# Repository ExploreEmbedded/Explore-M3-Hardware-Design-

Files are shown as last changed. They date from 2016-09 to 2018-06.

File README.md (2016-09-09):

# Explore-M3-Hardware-Design-

Explore M3 is a feature rich ARM Cortex M3 development board. It can help you prototype ideas faster with Arduino and take them beyond, with bare metal programming, RTOS support and lower power modes if need be. All the source-code and hardware design files are open-source including the on board boot-loader. This makes it easy in using the board/chip in your custom designs

explore m3

We are currently crowdfunding the board, click on the link below to support.
https://www.crowdsupply.com/explore-embedded/explore-m3

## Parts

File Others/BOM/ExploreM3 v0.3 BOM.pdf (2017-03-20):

Id Designator | | Package | units | Designation | Quantities
1 | P6 | 2.54 mm Pitch 8X1 | 1 | Male Pin headers | 50
2 | P7,P5 | 2.54 mm Pitch 20X1 | 1 | Male Pin headers | 50
3 | P1 | 2.54 mm Pitch 5X2 | 1 | Male Pin headers | 50
5 | D1,D3 | 0603 Package | 3 | Blue LED | 150
6 | D2 | 0603 Package | 1 | Red LED | 50
7 | F1 | 1206 Package | 1 | FUSE | 50
10 | Y1 | SMD ,3.2mm x 1.5mm | 1 | 32.768KHz Crystal | 50
11 | L1 | 0805 Package | 1 | Multilayer Ferrite Bead (7 ohm) | 50
14 | U2 | SOT-23-3 | 1 | BSS84 MOSFET | 50
17 | C5,C1,C2,C6,C7,C8 | 0603 Package | 6 | 0.1uF ceramic capacitors | 300
18 | R4,R5 | 0603 Package | 2 | 100E Resistors | 100
19 | C3,C4,C16,C18 | 0603 Package | 4 | 22pf Ceramic Capacitors | 200
20 | C10,C11 | 0603 Package | 2 | 18pF Ceramic Capacitors | 100
21 | C12 | 0603 Package | 1 | 1uF Ceramic Capacitors | 50
22 | C14 | 0603 Package | 1 | 0.1uF ceramic capacitors | 50
23 | C15 | 0603 Package | 1 | 2.2uf Ceramic Capacitors | 50
24 | R1,R8,R9,R10,R11,R12,R13,R20 | 0603 Package | 8 | 10K Resistors | 400
25 | R2,R19,R21,R22 | 0603 Package | 4 | 1K Resistors | 200
26 | R3 | 0603 Package | 1 | 150E Resistors | 50
27 | R6 | 0603 Package | 1 | 100K Resistors | 50
28 | R7,R14 | 0603 Package | 2 | 33R Resistors | 100
29 | R15 | 0603 Package | 1 | 1.5K Resistors | 50
Explore M3 v0.3 | Quantity | 50

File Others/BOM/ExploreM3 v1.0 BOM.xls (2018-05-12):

 | Explore M3 v1.0 | Quantity
Id | Designator | Package | Designation | Quantities | Link
1 | P6 | 2.54 mm Pitch 8X1 | Male Pin headers | 120
2 | P7,P5 | 2.54 mm Pitch 20X1 | Male Pin headers | 230
3 | P1 | 2.54 mm Pitch 5X2 | Male Pin headers | 120
4 | U3 | SMD | Micro USB connector | 50 | https://www.aliexpress.com/item/100pc-Micro-USB-5pin-B-type-0-8mm-Female-Connector-For-Mobile-Phone-Micro-USB-Jack/32648674955.html
7 | F1 | 1206 Package | FUSE | 120 | https://ae01.alicdn.com/kf/HTB1f23bNFXXXXbpXFXXq6xXFXXX8/10-Pcs-Per-Lot-Littelfuse-SMD-SMT-1206-Fast-Acting-Fuse-0-5A-500mA-63V-0466.jpg_640x640.jpg
8 | U1 | LQFP-100 | LPC1768FBD100 | 110
9 | U4 | SOT-23-5 | AP2112K | 120 | https://www.aliexpress.com/item/Brand-new-original-SOT23-5-AP2112K-3-3TRG1-patch-3-3V-LDO-600MA-regulator/32605944979.html
10 | Y1 | SMD ,3.2mm x 1.5mm | 32.768KHz Crystal | 115 | https://www.aliexpress.com/item/CC7V-T1K-FC-135-CM315-DST310S-3215-2P-32-768K-32-768KHZ-SMD-Crystal-Oscillator-x/1999550166.html
11 | L1 | 0805 Package | Multilayer Ferrite Bead (7 ohm) | 125 | https://www.aliexpress.com/item/Free-shipping-0805-SMD-ferrite-bead-600R-600-European-large-current-3A-500-Ge/32697359265.html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
12 | U6 | SMD , 3.2mm X 2.5mm | 12Mhz Crystal ( 4 pins) | 115 | https://www.aliexpress.com/item/12MHz-3-2x2-5-3225-passive-SMD-quartz-crystal-oscillator-YXSMDZ157/32241752377.html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
14 | U2 | SOT-23-3 | BSS84 MOSFET | 125
15 | SW1,SW2 | SMD 4 pin | Push button switch | 250 | https://www.aliexpress.com/item/200pcs-SMT-Momentary-Action-4-Pin-Terminals-Tactile-Switches-4x4x2-5mm/32354066123.html
17 | C5,C1,C2,C6,C7,C8 | 0603 Package | 0.1uF ceramic capacitors | 700
19 | C3,C4,C16,C18 | 0603 Package | 22pf Ceramic Capacitors | 500
20 | C10,C11 | 0603 Package | 18pF Ceramic Capacitors | 250
21 | C12 | 0603 Package | 1uF Ceramic Capacitors | 125
22 | C14 | 0603 Package | 0.1uF ceramic capacitors | 150
23 | C15 | 0603 Package | 2.2uf Ceramic Capacitors | 150
24 | R1,R8,R9,R10,R11,R12,R13,R20 | 0603 Package | 10K Resistors | 1000
25 | R2,R19,R21,R22 | 0603 Package | 1K Resistors | 500
26 | R3 | 0603 Package | 150E Resistors | 150
27 | R6 | 0603 Package | 100K Resistors | 150
28 | R7,R14 | 0603 Package | 33R Resistors | 250
29 | R15 | 0603 Package | 1.5K Resistors | 125

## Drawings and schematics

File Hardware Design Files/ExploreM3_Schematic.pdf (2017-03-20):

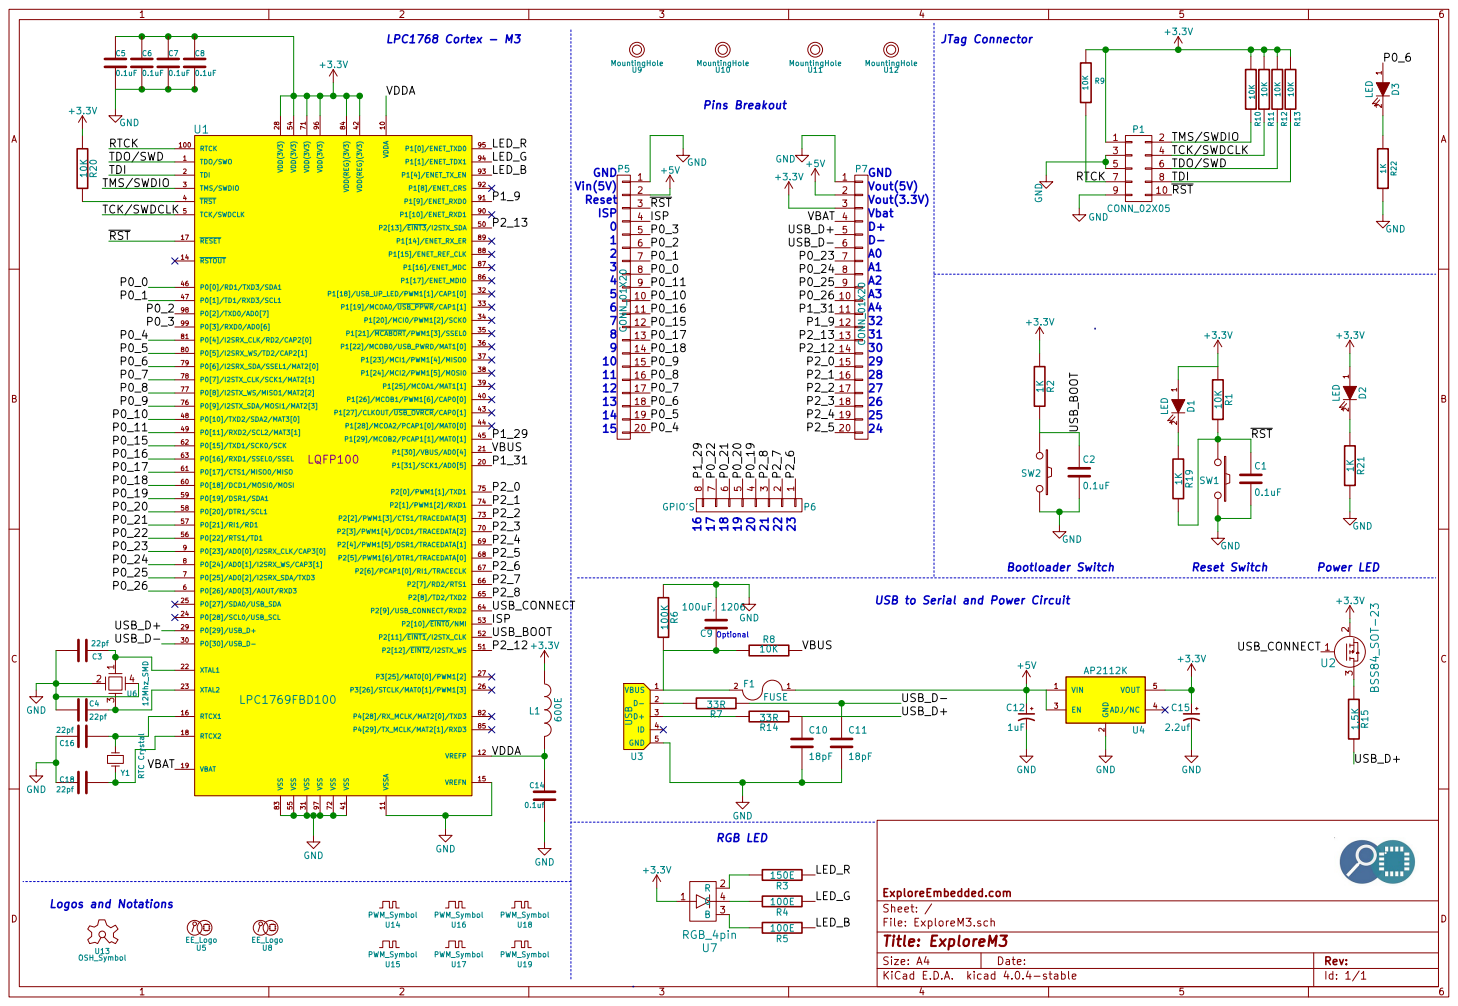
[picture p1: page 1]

U12 MountingHole U11 MountingHole U10 MountingHole U9 MountingHole

TCK/SWDCLK

2 EN 3 ADJ/NC 4 VOUT 5 U4 AP2112K

File: ExploreM3.sch Sheet: / ExploreEmbedded.com

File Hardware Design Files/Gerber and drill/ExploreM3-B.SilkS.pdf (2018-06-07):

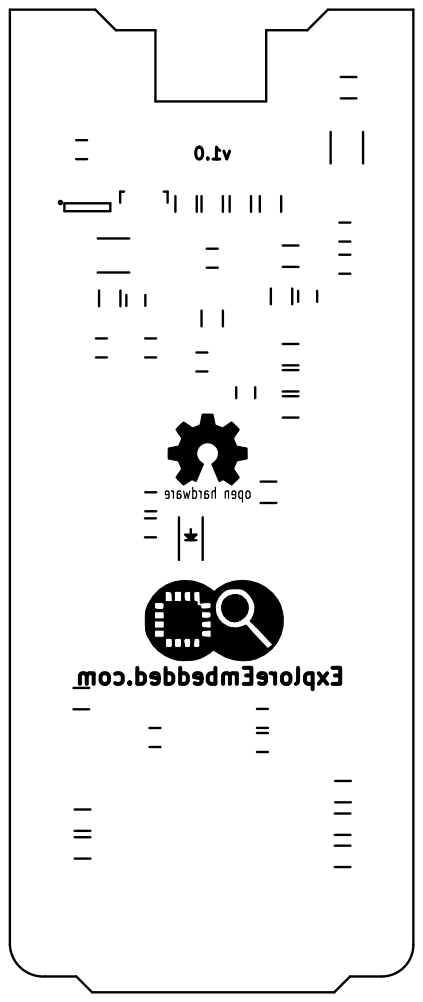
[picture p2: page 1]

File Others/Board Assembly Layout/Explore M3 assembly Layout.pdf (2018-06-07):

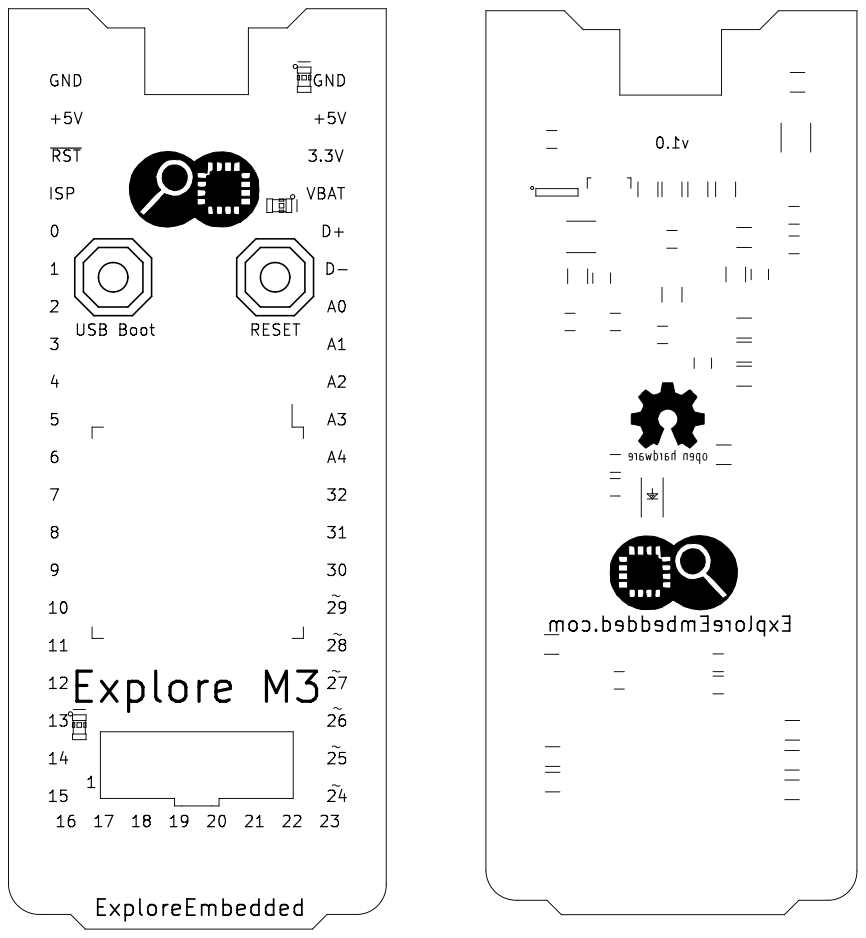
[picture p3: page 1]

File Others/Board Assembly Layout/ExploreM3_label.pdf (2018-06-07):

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

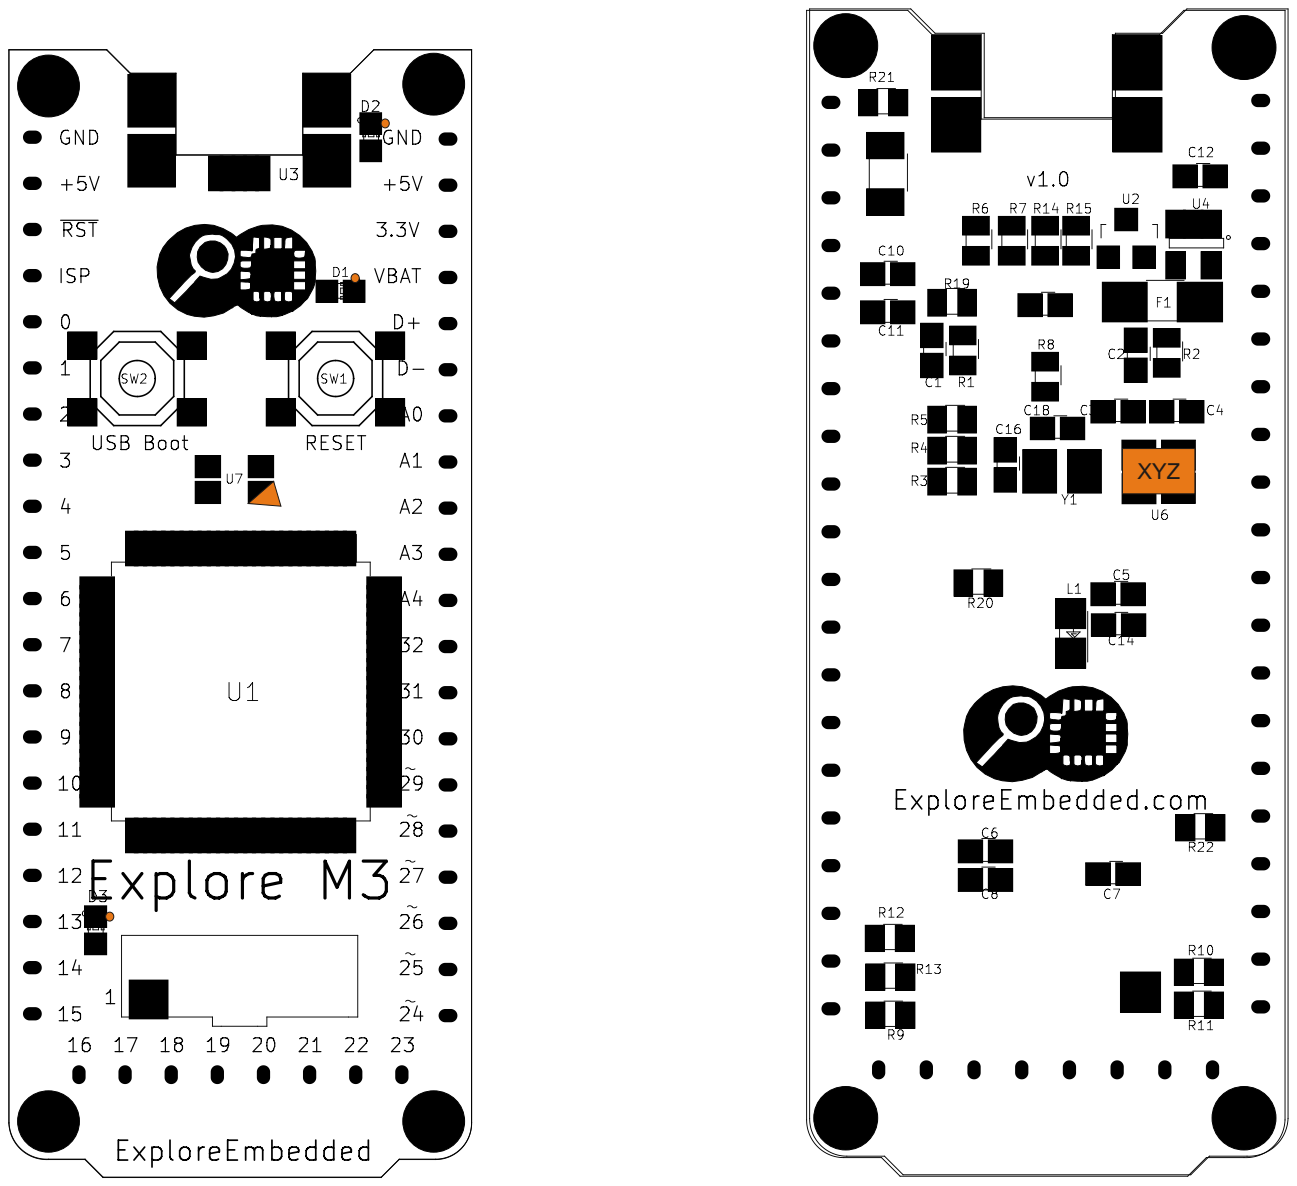
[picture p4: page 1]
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

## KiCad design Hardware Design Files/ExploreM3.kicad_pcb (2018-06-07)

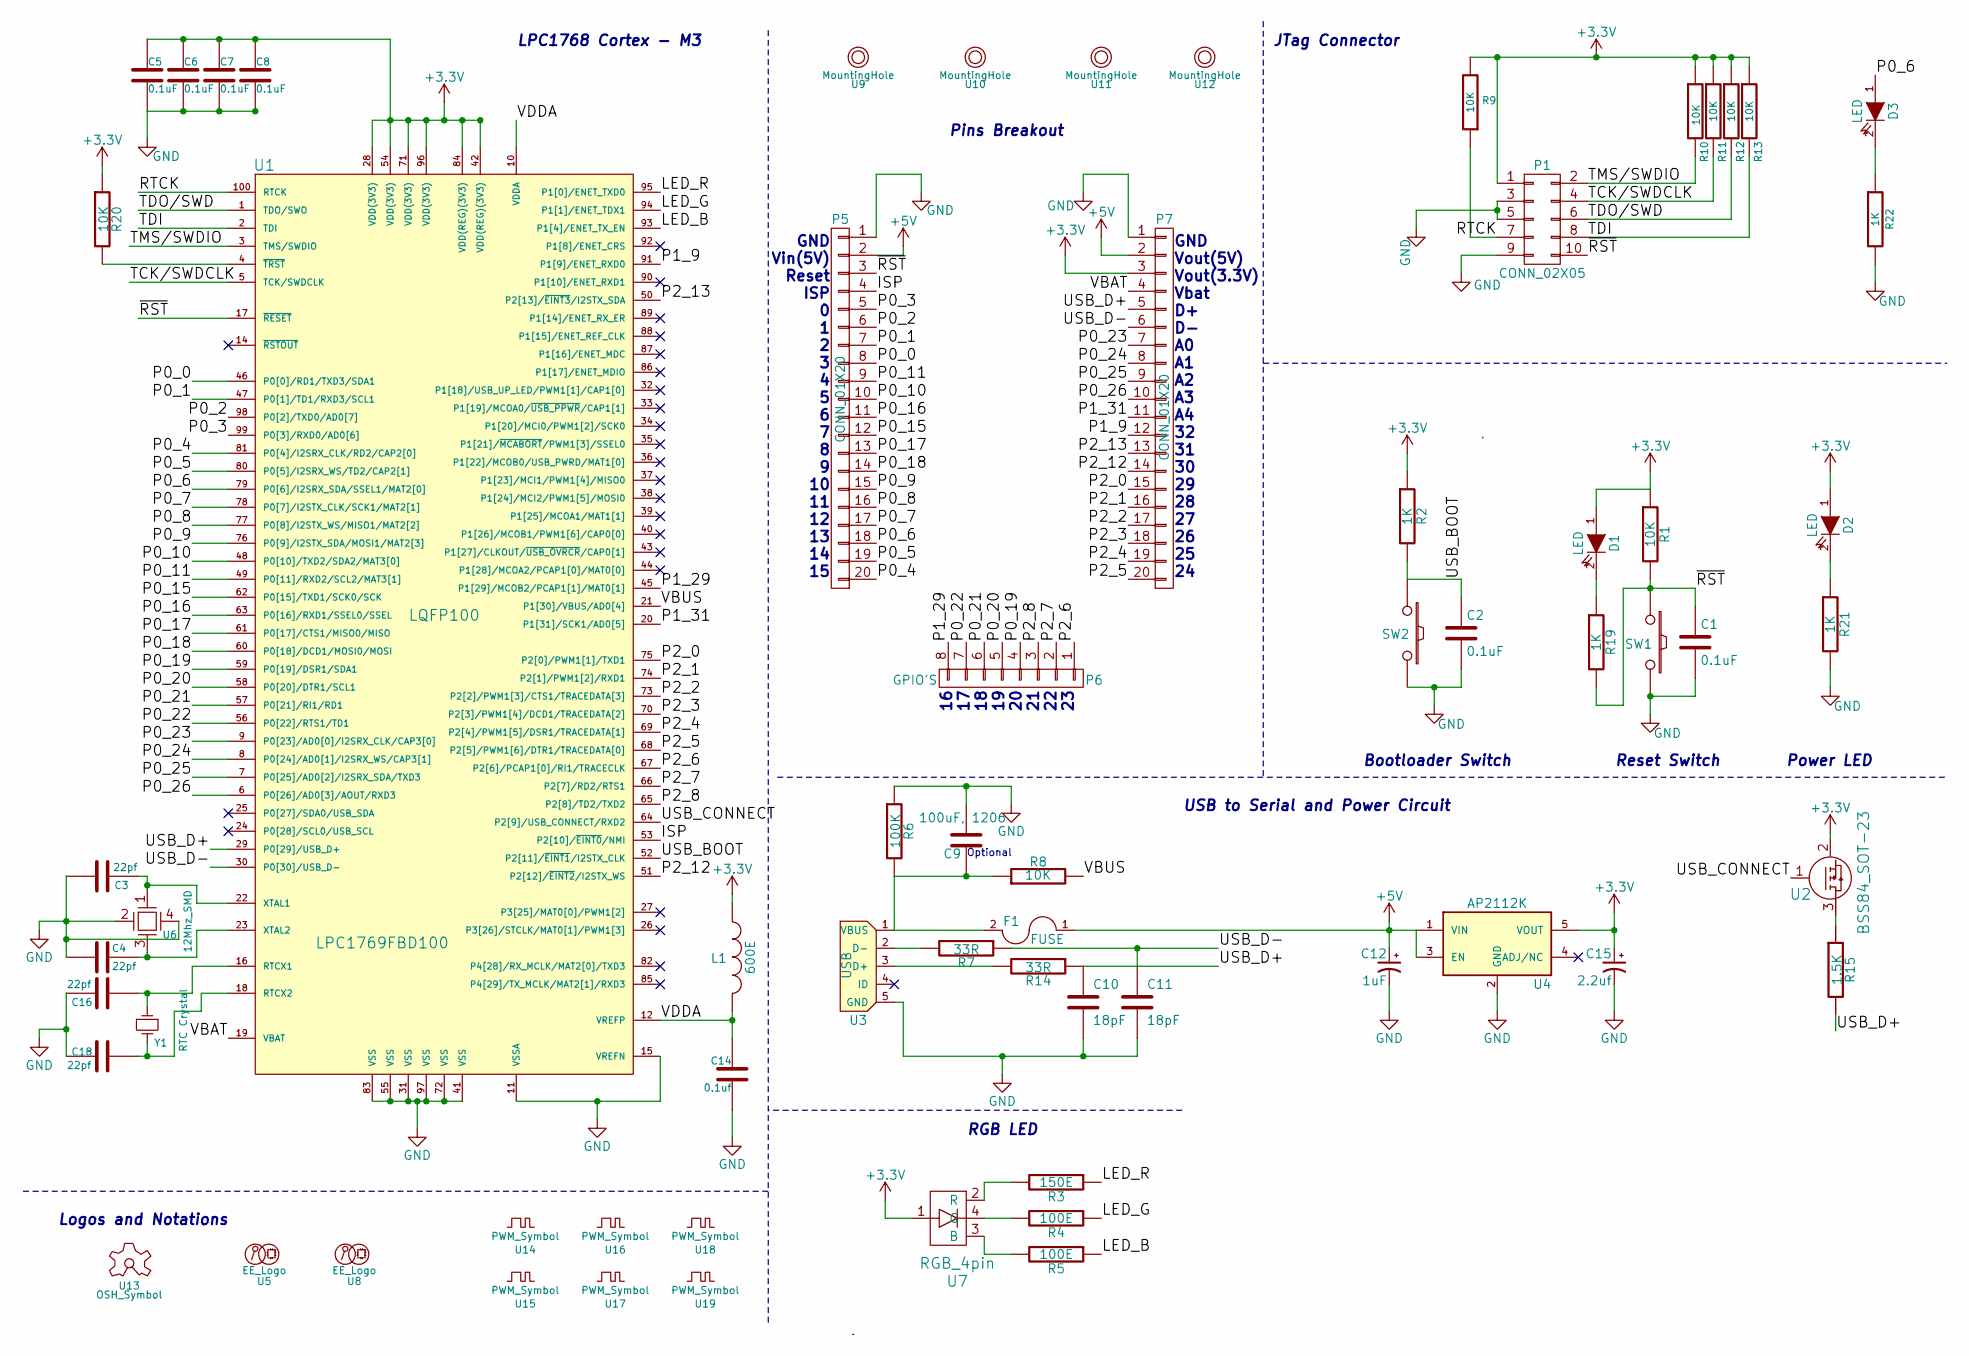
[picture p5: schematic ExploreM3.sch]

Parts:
C1, C2, C5, C6, C7, C8: 0.1uF
C3, C4, C16, C18: 22pf
C9: 100uF, 1206
C10, C11: 18pF
C12: 1uF
C14: 0.1uf
C15: 2.2uf
D1, D2, D3: LED
F1: FUSE
L1: 600E
P1: CONN_02X05
P5, P7: CONN_01X20
P6: GPIO'S
R1, R8, R9, R10, R11, R12, R13, R20: 10K
R2, R19, R21, R22: 1K
R3: 150E
R4, R5: 100E
R6: 100K
R7, R14: 33R
R15: 1.5K
SW1, SW2: SW_PUSH
U1: LPC1769FBD100; LQFP100
U2: BSS84_SOT-23
U3: USB
U4: AP2112K; SOT-23-5
U5, U8: EE_Logo
U6: 12Mhz_SMD
U7: RGB_4pin
U9, U10, U11, U12: MountingHole
U13: OSH_Symbol
U14, U15, U16, U17, U18, U19: PWM_Symbol
Y1: RTC Crystal

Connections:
+3V3: C5.1, C6.1, C7.1, C8.1, C15.1, D1.1 (A), D2.1 (A), L1.1, P1.1, P7.3, R1.1, R2.1, R9.2, R10.1, R11.1, R12.1, R13.1, R20.1, U1.28 (VDD(3V3)), U1.42 (VDD(REG)(3V3)), U1.54 (VDD(3V3)), U1.71 (VDD(3V3)), U1.84 (VDD(REG)(3V3)), U1.96 (VDD(3V3)), U2.2, U4.5 (VOUT), U7.1
+5V: C12.1, F1.1, P5.2, P7.2, U4.1 (VIN), U4.3 (EN)
/ISP: P5.4, U1.53 (P2[10]/~EINT0~/NMI)
/LED_B: R5.1, U1.93 (P1[4]/ENET_TX_EN)
/LED_G: R4.1, U1.94 (P1[1]/ENET_TDX1)
/LED_R: R3.1, U1.95 (P1[0]/ENET_TXD0)
/P0_0: P5.8, U1.46 (P0[0]/RD1/TXD3/SDA1)
/P0_1: P5.7, U1.47 (P0[1]/TD1/RXD3/SCL1)
/P0_2: P5.6, U1.98 (P0[2]/TXD0/AD0[7])
/P0_3: P5.5, U1.99 (P0[3]/RXD0/AD0[6])
/P0_4: P5.20, U1.81 (P0[4]/I2SRX_CLK/RD2/CAP2[0])
/P0_5: P5.19, U1.80 (P0[5]/I2SRX_WS/TD2/CAP2[1])
/P0_6: D3.1 (A), P5.18, U1.79 (P0[6]/I2SRX_SDA/SSEL1/MAT2[0])
/P0_7: P5.17, U1.78 (P0[7]/I2STX_CLK/SCK1/MAT2[1])
/P0_8: P5.16, U1.77 (P0[8]/I2STX_WS/MISO1/MAT2[2])
/P0_9: P5.15, U1.76 (P0[9]/I2STX_SDA/MOSI1/MAT2[3])
/P0_10: P5.10, U1.48 (P0[10]/TXD2/SDA2/MAT3[0])
/P0_11: P5.9, U1.49 (P0[11]/RXD2/SCL2/MAT3[1])
/P0_15: P5.12, U1.62 (P0[15]/TXD1/SCK0/SCK)
/P0_16: P5.11, U1.63 (P0[16]/RXD1/SSEL0/SSEL)
/P0_17: P5.13, U1.61 (P0[17]/CTS1/MISO0/MISO)
/P0_18: P5.14, U1.60 (P0[18]/DCD1/MOSI0/MOSI)
/P0_19: P6.4, U1.59 (P0[19]/DSR1/SDA1)
/P0_20: P6.5, U1.58 (P0[20]/DTR1/SCL1)
/P0_21: P6.6, U1.57 (P0[21]/RI1/RD1)
/P0_22: P6.7, U1.56 (P0[22]/RTS1/TD1)
/P0_23: P7.7, U1.9 (P0[23]/AD0[0]/I2SRX_CLK/CAP3[0])
/P0_24: P7.8, U1.8 (P0[24]/AD0[1]/I2SRX_WS/CAP3[1])
/P0_25: P7.9, U1.7 (P0[25]/AD0[2]/I2SRX_SDA/TXD3)
/P0_26: P7.10, U1.6 (P0[26]/AD0[3]/AOUT/RXD3)
/P1_9: P7.12, U1.91 (P1[9]/ENET_RXD0)
/P1_29: P6.8, U1.45 (P1[29]/MCOB2/PCAP1[1]/MAT0[1])
/P1_31: P7.11, U1.20 (P1[31]/SCK1/AD0[5])
/P2_0: P7.15, U1.75 (P2[0]/PWM1[1]/TXD1)
/P2_1: P7.16, U1.74 (P2[1]/PWM1[2]/RXD1)
/P2_2: P7.17, U1.73 (P2[2]/PWM1[3]/CTS1/TRACEDATA[3])
/P2_3: P7.18, U1.70 (P2[3]/PWM1[4]/DCD1/TRACEDATA[2])
/P2_4: P7.19, U1.69 (P2[4]/PWM1[5]/DSR1/TRACEDATA[1])
/P2_5: P7.20, U1.68 (P2[5]/PWM1[6]/DTR1/TRACEDATA[0])
/P2_6: P6.1, U1.67 (P2[6]/PCAP1[0]/RI1/TRACECLK)
/P2_7: P6.2, U1.66 (P2[7]/RD2/RTS1)
/P2_8: P6.3, U1.65 (P2[8]/TD2/TXD2)
/P2_12: P7.14, U1.51 (P2[12]/~EINT2~/I2STX_WS)
/P2_13: P7.13, U1.50 (P2[13]/~EINT3~/I2STX_SDA)
/RTCK: P1.7, R9.1, U1.100 (RTCK)
/TCK/SWDCLK: P1.4, R11.2, U1.5 (TCK/SWDCLK)
/TDI: P1.8, R13.2, U1.2 (TDI)
/TDO/SWD: P1.6, R12.2, U1.1 (TDO/SWO)
/TMS/SWDIO: P1.2, R10.2, U1.3 (TMS/SWDIO)
/USB_BOOT: C2.1, R2.2, SW2.1, U1.52 (P2[11]/~EINT1~/I2STX_CLK)
/USB_CONNECT: U1.64 (P2[9]/USB_CONNECT/RXD2), U2.1
/USB_D+: C10.1, P7.5, R14.1, R15.2, U1.29 (P0[29]/USB_D+)
/USB_D-: C11.1, P7.6, R7.1, U1.30 (P0[30]/USB_D-)
/VBAT: P7.4, U1.19 (VBAT)
/VBUS: R8.2, U1.21 (P1[30]/VBUS/AD0[4])
/VDDA: C14.2, L1.2, U1.10 (VDDA), U1.12 (VREFP)
/~RST: C1.1, P1.10, P5.3, R1.2, R19.2, SW1.1, U1.17 (~RESET~)
GND: C1.2, C2.2, C3.1, C4.2, C5.2, C6.2, C7.2, C8.2, C9.2, C10.2, C11.2, C12.2, C14.1, C15.2, C16.2, C18.2, P1.3, P1.5, P1.9, P5.1, P7.1, R6.1, R21.2, R22.2, SW1.2, SW2.2, U1.11 (VSSA), U1.15 (VREFN), U1.31 (VSS), U1.41 (VSS), U1.55 (VSS), U1.72 (VSS), U1.83 (VSS), U1.97 (VSS), U3.5 (GND), U4.2 (GND), U6.2, U6.4
unnamed: C3.2, U1.22 (XTAL1), U6.1
unnamed: C4.1, U1.23 (XTAL2), U6.3
unnamed: C9.1, F1.2, R6.2, R8.1, U3.1 (VBUS)
unnamed: C16.1, U1.16 (RTCX1), Y1.1
unnamed: C18.1, U1.18 (RTCX2), Y1.2
unnamed: D1.2 (K), R19.1
unnamed: D2.2 (K), R21.1
unnamed: D3.2 (K), R22.1
unnamed: R3.2, U7.2 (R)
unnamed: R4.2, U7.4 (G)
unnamed: R5.2, U7.3 (B)
unnamed: R7.2, U3.2 (D-)
unnamed: R14.2, U3.3 (D+)
unnamed: R15.1, U2.3
unnamed: R20.2, U1.4 (~TRST~)

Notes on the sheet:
LPC1768 Cortex - M3
GND Vin(5V) Reset ISP 0 1 2 3 4 5 6 7 8 9 10 11 12 13 14 15
GND Vout(5V) Vout(3.3V) Vbat D+ D- A0 A1 A2 A3 A4 32 31 30 29 28 27 26 25 24
16 17 18 19 20 21 22 23
Optional
Logos and Notations
JTag Connector
Bootloader Switch
Reset Switch
Power LED
Pins Breakout
USB to Serial and Power Circuit
RGB LED

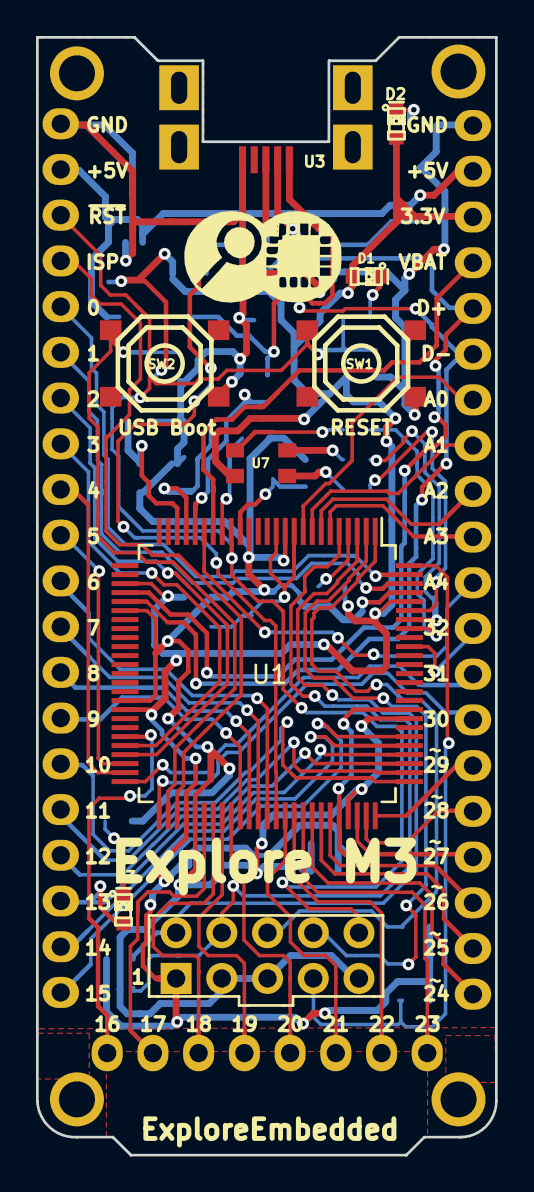
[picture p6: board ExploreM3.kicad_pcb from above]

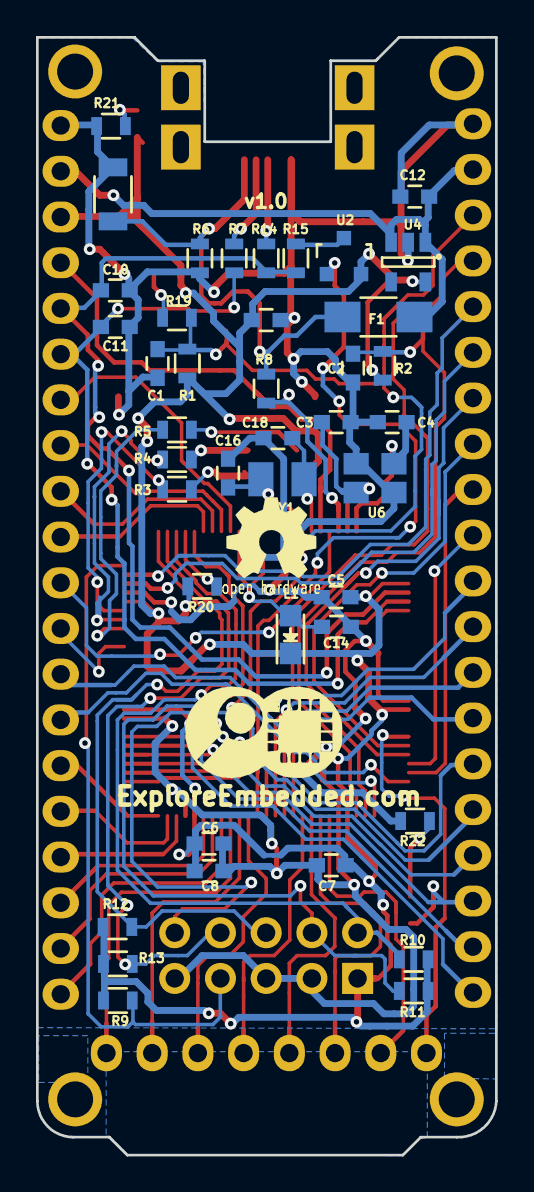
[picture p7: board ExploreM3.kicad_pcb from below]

Board: 2 copper layers, 25.5 x 62.1 mm, 66 parts (46 on the bottom side), 73 nets.

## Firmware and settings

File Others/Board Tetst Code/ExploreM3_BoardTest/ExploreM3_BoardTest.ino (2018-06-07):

#include "RTC.h"

RTC my_rtc;

char daysOfTheWeek[7][12] = {"Sunday", "Monday", "Tuesday", "Wednesday", "Thursday", "Friday", "Saturday"};



char option;
int max = 41, i, j;

void gpio_Test();
void adc_test();
void rtc_test();


int key()
{
  if (digitalRead(41)== 1)
    return 1;
  else
  {
    while (digitalRead(41) == 0);
    return 0;
  }
}

void setup()
{
  Serial.begin(9600);
  pinMode(41, INPUT);
  while (key());
  Serial.println(' ');
  Serial.println(' ');
  Serial.println("------------------------------------");
  Serial.println(F("Testing Explore Arduino"));
  Serial.println(F("Press-->1 for GPIO Test"));
  Serial.println(F("Press-->2 for Serial Test"));
  Serial.println(F("Press-->3 for ADC Test"));
  Serial.println(F("Press-->4 for RTC Test"));
  Serial.println(F("Select One of the above options"));
  Serial.println("------------------------------------");
  Serial.println(' ');
  option = '1';
}

void loop()
{
  switch (option)
  {
    case '1': gpio_Test(); break;
    case '2': serial_test(); break;
    case '3': adc_test(); break;
    case '4': rtc_test(); break;

  }
  option++;
  if (option > '5')
  option = '1';
}

void gpio_Test()
{
  for (i = 0; i < max; i++)
  {
    pinMode(i, OUTPUT);
    digitalWrite(i, HIGH);
  }

  int keyPress = key();
  while (keyPress)
  {

    for (i = 0; ((i < max) && keyPress); i++)
    {
      keyPress = key();
      digitalWrite(i, LOW);
      delay(100);
      digitalWrite(i, HIGH);
      delay(100);
    }
  }
}


void serial_test()
{
  Serial.println(F("DO the serial connection M3-Tx pins 1,3,5,7 to Cp2102 Rx pins"));
  Serial.println(F("Make connections and hit 'k' to test "));

  Serial0.begin(9600);
  Serial1.begin(9600);
  Serial2.begin(9600);
  Serial3.begin(9600);

  while (key())
  {
    Serial0.println("Serial port Zero");
    Serial1.println("Serial port One");
    Serial2.println("Serial port Two");
    Serial3.println("Serial port Three");
  }
}




void adc_test()
{
  int sensorValue;

  Serial.println(F("Connect Temp Sensor to A0, POT->A1 and LDR->A2"));

  while (key())
  {
    sensorValue = analogRead(A0);
    Serial.print("Temp Sensor = " );
    Serial.print(sensorValue);

    sensorValue = analogRead(A1);
    Serial.print("  POT = " );
    Serial.print(sensorValue);

    sensorValue = analogRead(A2);
    Serial.print("  LDR = " );
    Serial.println(sensorValue);
    delay(500);
  }
}


void rtc_test()
{
  my_rtc.begin();

  if (! my_rtc.isrunning()) {
    Serial.println("RTC is NOT running!");
    // following line sets the RTC to the date & time this sketch was compiled
    my_rtc.adjust(DateTime((__DATE__), (__TIME__)));
    // This line sets the RTC with an explicit date & time, for example to set
    // January 21, 2014 at 3am you would call:
    // my_rtc.adjust(DateTime(2014, 1, 21, 3, 0, 0));
  }

  while (key())
  {

    DateTime now = my_rtc.now();

    Serial.print(now.year(), DEC);
    Serial.print('/');
    Serial.print(now.month(), DEC);
    Serial.print('/');
    Serial.print(now.day(), DEC);
    Serial.print(" (");
    Serial.print(daysOfTheWeek[now.dayOfTheWeek()]);
    Serial.print(") ");
    Serial.print(now.hour(), DEC);
    Serial.print(':');
    Serial.print(now.minute(), DEC);
    Serial.print(':');
    Serial.print(now.second(), DEC);
    Serial.println();

    Serial.print(" since midnight 1/1/1970 = ");
    Serial.print(now.unixtime());
    Serial.print("s = ");
    Serial.print(now.unixtime() / 86400L);
    Serial.println("d");

    // calculate a date which is 7 days and 30 seconds into the future
    DateTime future (now + TimeSpan(7, 12, 30, 6));

    Serial.print(" now + 7d + 30s: ");
    Serial.print(future.year(), DEC);
    Serial.print('/');
    Serial.print(future.month(), DEC);
    Serial.print('/');
    Serial.print(future.day(), DEC);
    Serial.print(' ');
    Serial.print(future.hour(), DEC);
    Serial.print(':');
    Serial.print(future.minute(), DEC);
    Serial.print(':');
    Serial.print(future.second(), DEC);
    Serial.println();

    Serial.println();
    delay(1000);

  }
}

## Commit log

2016-09-09 Design Files
    [ExploreM3.kicad_pcb, ExploreM3.sch]
2016-09-20 Added filled zones
    [ExploreM3.kicad_pcb]
2016-10-08 Moved LED
    [ExploreM3.kicad_pcb]
2016-10-10 Version name modified on Silkscreen
    [ExploreM3.kicad_pcb]
2017-03-20 BOM added
    [ExploreM3 v0.3 BOM.xls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]
2018-05-11 Revised BOM
    [ExploreM3 v0.3 BOM.xls]
2018-05-12 Boards are arranged in the Panel
    [ExploreM3 v1.0 BOM.xls]
2018-06-07 Board Test code added
    1. Footprint labels added
    2. Board Test coded added
    [ExploreM3.kicad_pcb]
